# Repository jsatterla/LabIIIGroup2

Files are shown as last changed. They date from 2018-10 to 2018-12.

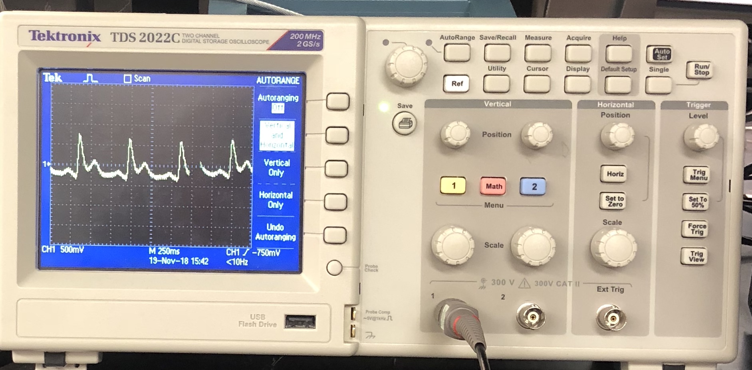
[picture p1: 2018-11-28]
Biomedical/EKG/Best Oscilloscope Reading.JPG

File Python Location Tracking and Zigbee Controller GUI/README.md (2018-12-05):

Python 3.7 program communicating with TI CC2640R2F LaunchPad for location tracking with Time of Flight. Sends network commands to XBee interfaced via RS232 breakout board. Uses pyserial for serial communication to XBee and CC2640R2F LaunchPad, and TkInter package for GUI.

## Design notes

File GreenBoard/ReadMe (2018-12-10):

## this file is of no importance. However, the green board files contained within this are slighly. lol

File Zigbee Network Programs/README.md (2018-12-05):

Folder for 2 MSP430 programs that control the model home's devices.

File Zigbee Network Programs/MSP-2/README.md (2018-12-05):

C program for MSP430 controlling 1 stepper motor and 1 BS170 n channel FET.

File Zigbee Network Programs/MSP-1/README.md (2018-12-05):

MSP #1 program to control 4 LED's and 1 computer fan

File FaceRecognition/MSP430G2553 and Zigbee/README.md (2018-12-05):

This folder contains the files to communicate MSP430 microcontroller with Zigbee module to open a door with stepper motor.

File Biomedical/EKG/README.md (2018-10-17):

Information and schematics related to the EKG portion of the project

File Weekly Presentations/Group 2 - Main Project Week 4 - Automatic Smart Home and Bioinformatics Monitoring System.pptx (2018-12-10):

## SMART Home

Group 2:
John Satterla [Team Lead] – Computer Engineer – Wireless Connectivity
Zachary Eakerns – Electrical Engineer – Biomedical Station
Zarka McClung – Computer Engineer – Facial Recognition
Christian Jensen – Electrical Engineer – Voice Recognition

## Last Week's Deliverables

John Satterla

- Test ToF Launchpads for accuracy depending on environment
- Develop Zigbee network protocol for sending and receiving meaningful data

Zachary Eakerns

- Built and begin testing filters
- Begin writing and testing software for peak detection

Zarka McClung

- Research Algorithm and try to implement it
- Completed webcam code to test Algorithm with face detection code

Christian Jensen

- Design and order parts for relay circuit
- Research Raspberry Pi Smart home front ends

## System Overview

LEDs to represent Lights

LCD screen represents TV

Door can be opened automatically via facial recognition or control from central processing station via Zigbee

Full size automatic door with facial recognition

Small Scale House Model

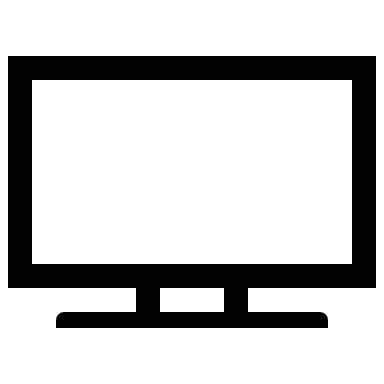
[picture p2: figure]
Television

Biomedical Station

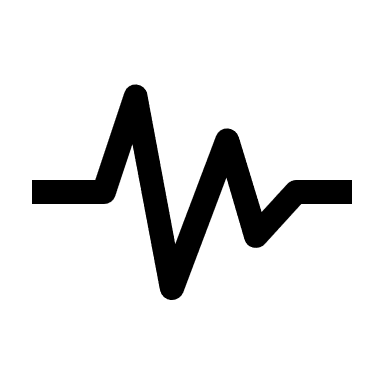
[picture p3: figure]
Heartbeat

Biomedical station gets EKG, heart rate, and blood oxygenation of the user, relays information to the Central processing station. Zigbee module takes commands from central processing station to control devices

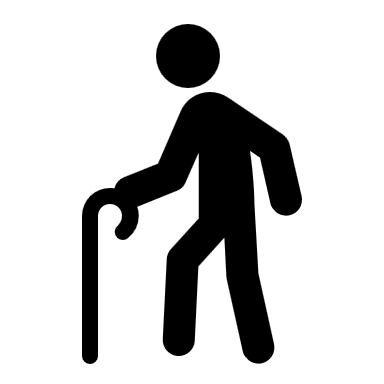
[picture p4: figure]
Person with Cane
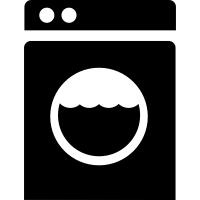
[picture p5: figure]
Image result for washer icon

Computer fan to represent ceiling fan

Servo based washer representation

Portable Location Detection Device

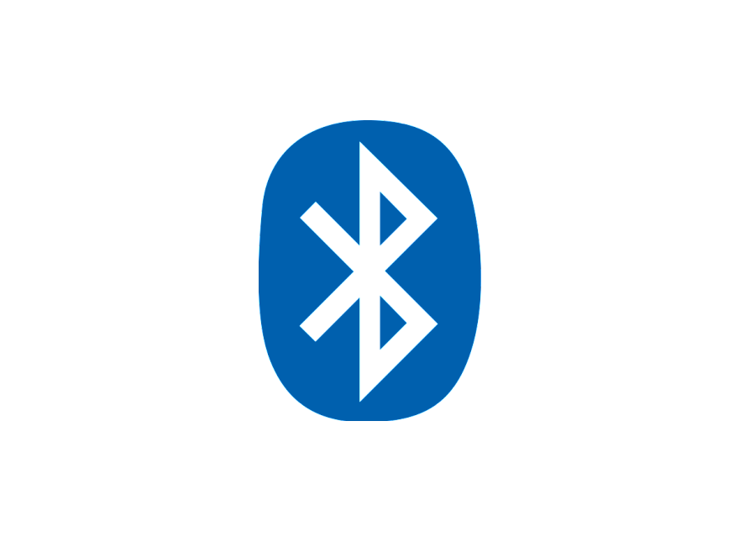
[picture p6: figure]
Image result for bluetooth logo

Portable BLE Time of Flight device reacts to movements of user throughout the room and devices turn on inside the small scale model

Central processing Station, with Voice Recognition

Central processing station (computer) displays system information and can control devices via voice commands. Communicates with rest of devices via Zigbee

Bluetooth ToF Beacon

Zigbee Module

Microcontroller

John Satterla

## Tracking Location of the Patient Monitor

- Ideally work indoors, so using GPS not preferred because of accuracy and not able to get fix inside of buildings
- BLE ToF – Bluetooth Time of Flight
  - Time of Flight is used to estimate range by measuring the round trip delay of an RF packet exchange
  - At least two devices needed, and operate generally as a master and a slave, where the master calculates average round trip delay for hundreds of packets to be as accurate as possible (try to reduce error from interference, other RF related differences) [ref]

John Satterla

## Bluetooth Time of Flight

- Experimental Bluetooth Time of Flight stack from Texas Instruments allows patients location to be tracked by calculating the round-trip time and RSSI of packets from the ToF initiator and responder

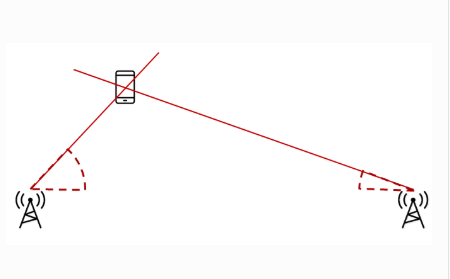
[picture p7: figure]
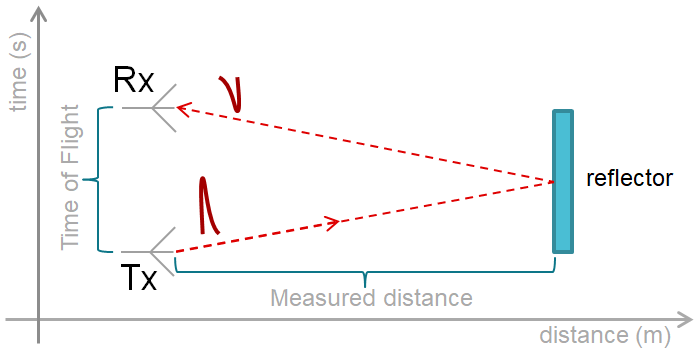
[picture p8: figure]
A screenshot of a cell phone Description generated with very high confidence

ToF Responder

ToF Initiator

[1]

John Satterla

## BLE ToF – Further Testing

- Testing was done to see if interference was cause of problem with location returning negative values
- Testing was to no success after testing in environment with limited 2.4GHz interference, although it did seem better than basement lab
- In contact with TI on how to improve performance, was directed to some optimization tools in the software that will be tested this week

John Satterla

## BLE ToF – Further Testing

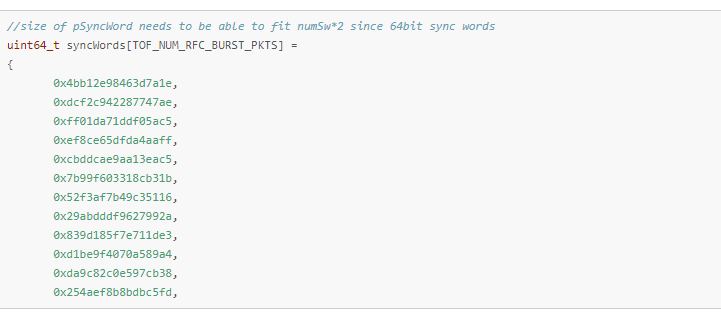
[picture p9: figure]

Going to try and increase the number of syncwords, which serve as almost ‘ACKs’ that sync each ToF flight packet with each other

[2]

John Satterla

## Changing Software

- Using Code Composer Studio in conjunction with launchpad is far too slow to accurately graph data every 2 ms for EKG readings
- To fix this, research into using Python along with UART communication via BlueSMiRF is underway
- Microcontroller will still be coded in Code Composer Studio, however receiving data and graphing it will be done through Python

## Python

- Data can be graphed quickly in Python by using the matplotlib library
- Python will store the data received by the BlueSMiRF [1] into a vector and then graph the value
- Things to be mindful of include making sure baud rate of both the communication method and the microcontroller are sufficient, and that vector can delete past values incase the machine is left on for a long amount of time

## Matplotlib

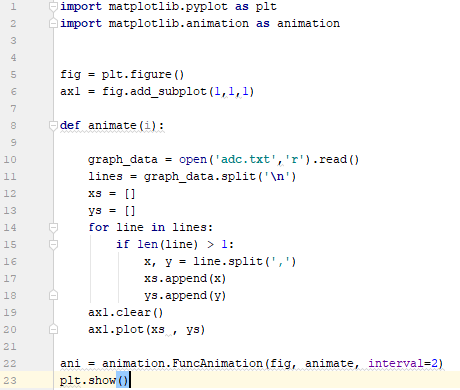
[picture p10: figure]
A screenshot of a social media post Description generated with very high confidence
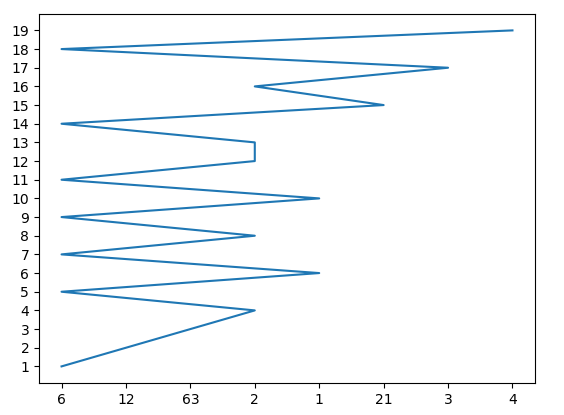
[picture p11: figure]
A close up of a logo Description generated with very high confidence

## Instability In Circuitry

- While amplification circuit seems to work, as well as the filters removing transmission line noise, the output is unstable at lower frequencies, varying by as much as 20%
- Could be due to breadboard, faulty parts, or faulty measuring equipment
- Further work will go into identifying issue once code catches up since switching to Python created a setback

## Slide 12

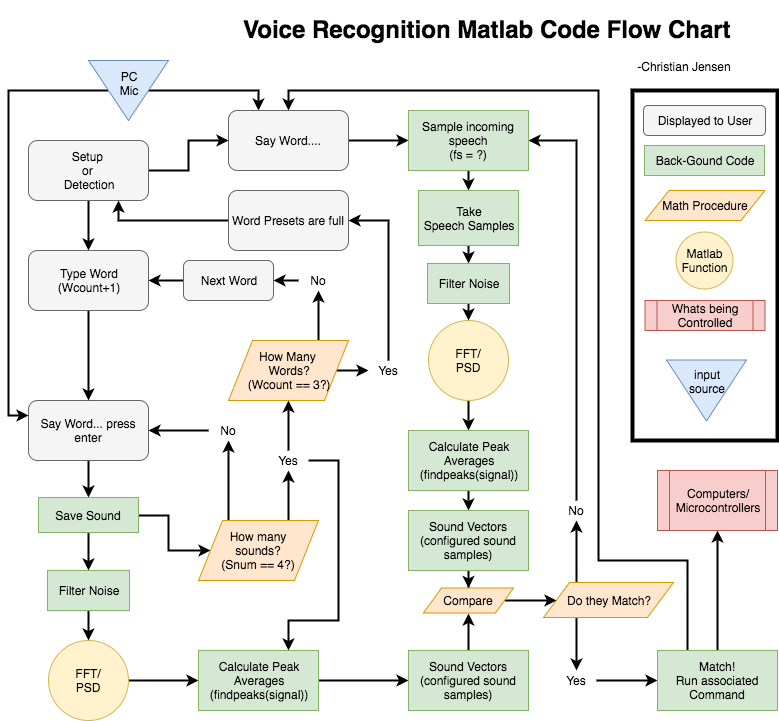
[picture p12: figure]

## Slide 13

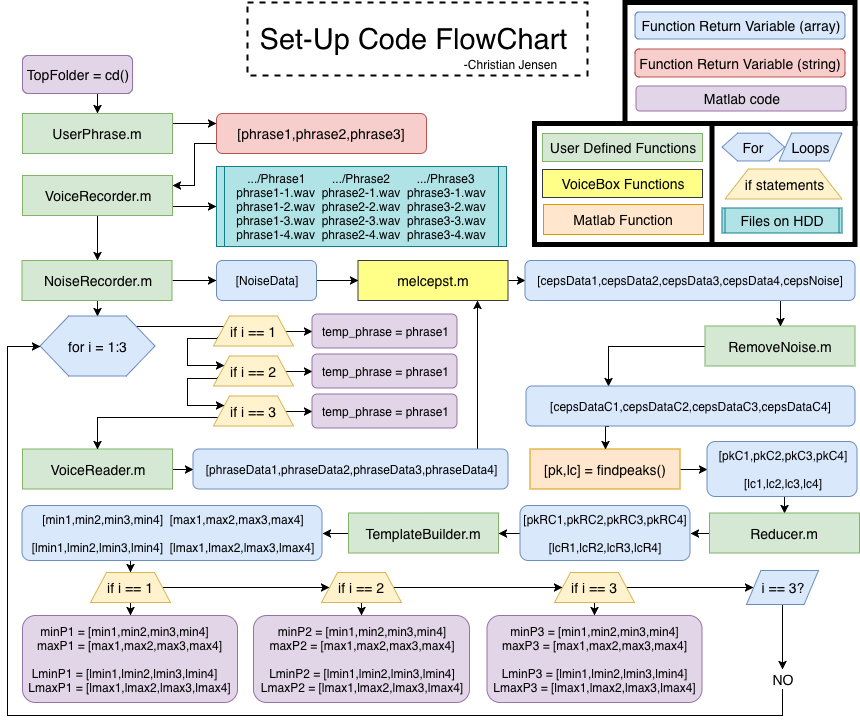
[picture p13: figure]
A screenshot of a parking meter Description generated with high confidence

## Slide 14

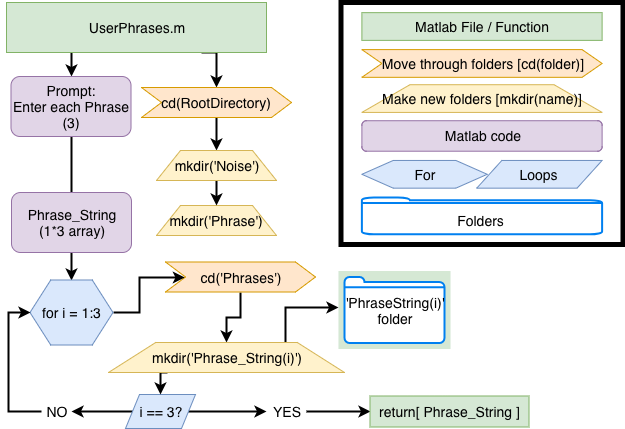
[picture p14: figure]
A screenshot of a cell phone Description generated with very high confidence

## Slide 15

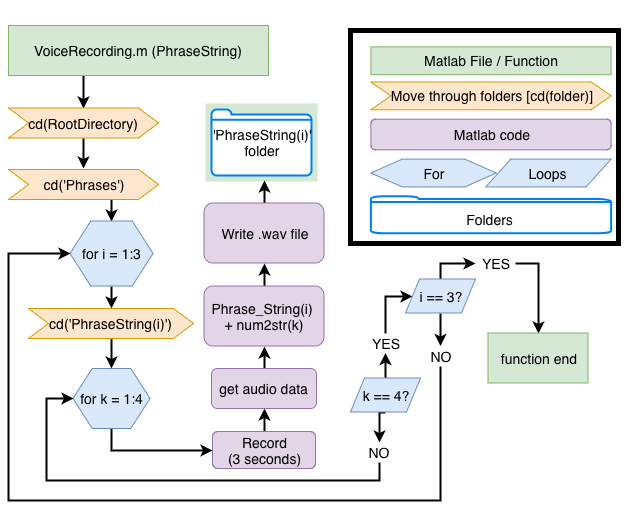
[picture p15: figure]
A screenshot of a cell phone Description generated with very high confidence

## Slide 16

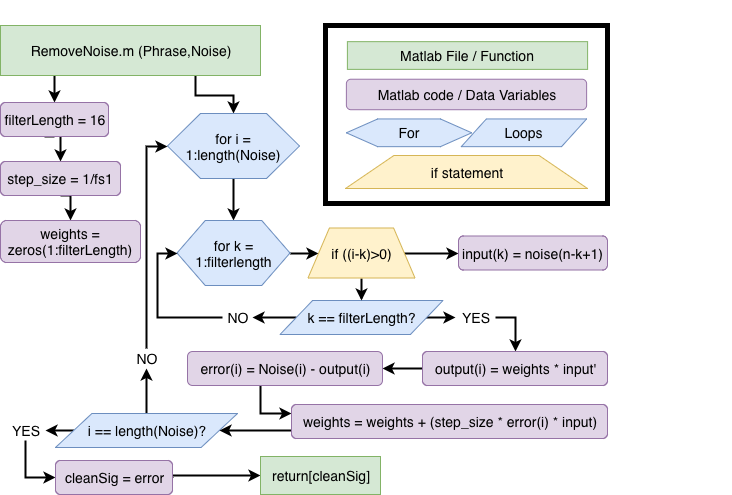
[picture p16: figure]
A screenshot of a cell phone Description generated with very high confidence

Least Mean Squared adaptive filter

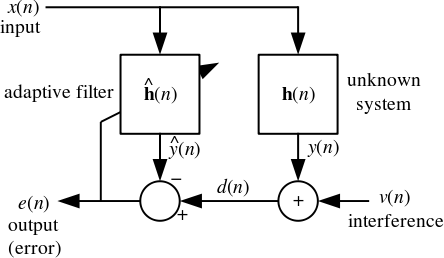
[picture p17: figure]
A close up of a logo Description generated with very high confidence

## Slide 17

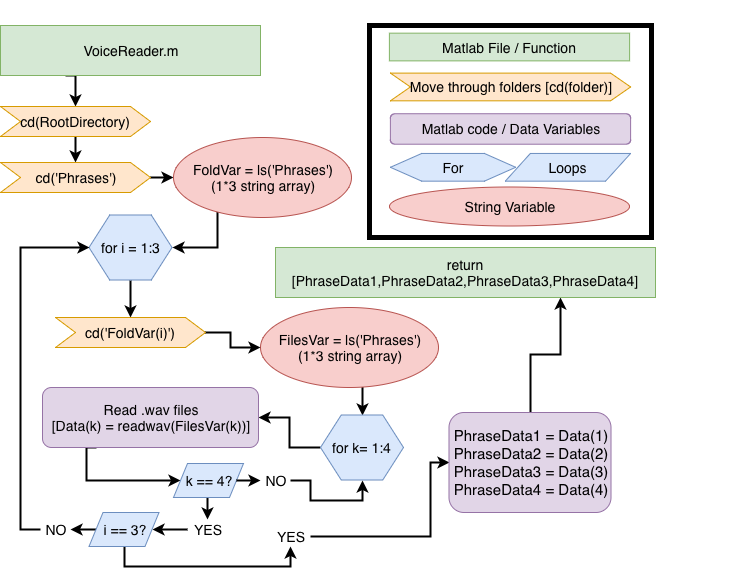
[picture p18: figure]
A screenshot of a cell phone Description generated with very high confidence

## Cepstrum

- C[n] = Cepstrum
  - IDFT of Log-spectrum over time
  - Inverse of frequency called Quefrecy

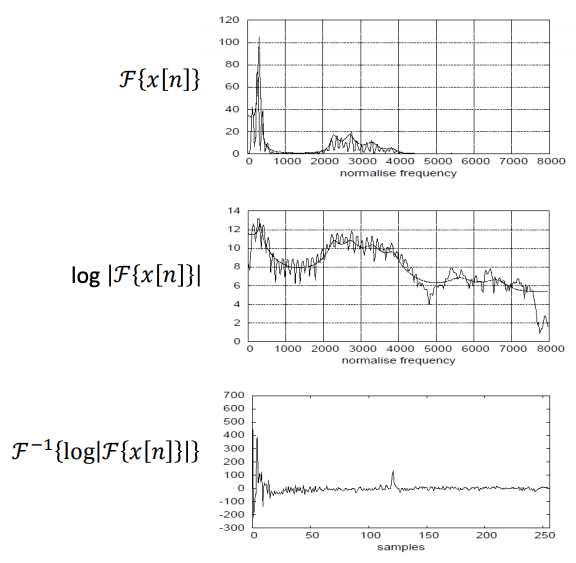
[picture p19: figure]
A close up of a map Description generated with high confidence

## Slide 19

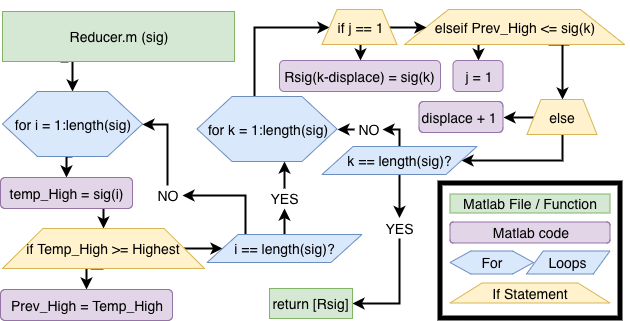
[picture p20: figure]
A screenshot of a cell phone Description generated with very high confidence
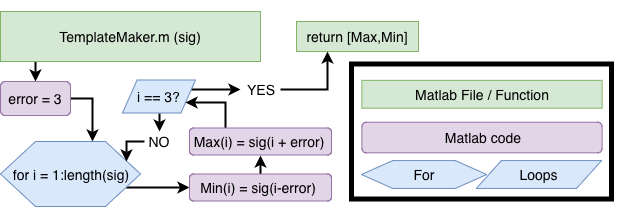
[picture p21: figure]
A screenshot of a cell phone Description generated with very high confidence

## Voice Recognition Methods

Process:
1. Ask user to set up phrases before
  1. Type name of phrase
  2. Speak the phrase (3x times)
  3. Find the PSD of the signal
  4. Set peaks as template
2. Speech recognition
  1. Poll for incoming phrases
  2. Sample input
  3. Find the PSD of the signal
  4. Compare peaks with Template

- Matlab [7]
  - Using the computer and its microphone to detect voice
    - Allows for easier integration with the entire project
    - Using the Voicebox Toolbox [9]
    - Contains many voice and audio related functions

*The system will be speaker dependent
(Only recognizing one specific person's commands)

## Update on Face Recognition and Hardware

- Completed Face Recognition software to detect user successfully. Will be tweaking it more down the road after main goal to open the door is completed.
- Currently working on best route to send wireless signal to open the door for the user.
- Will be using Zigbee module (ordered through stockroom) to send command to Master Zigbee Module (John's Zigbee), then Master module will send command to MCU to open the door
- Researching on methods, which motor to use to open the door.
- Will be working on code for Computer to Zigbee communication
- Once goal is accomplished, will be working on facial gesture detection to make recognition more secure

## Gantt Chart

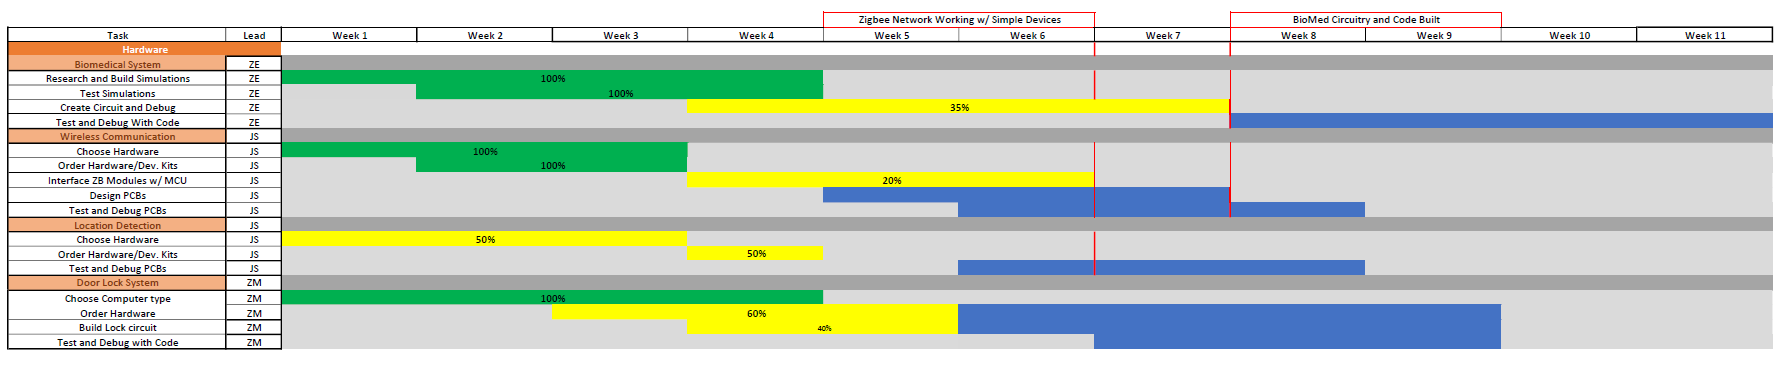
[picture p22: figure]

## Gantt Chart

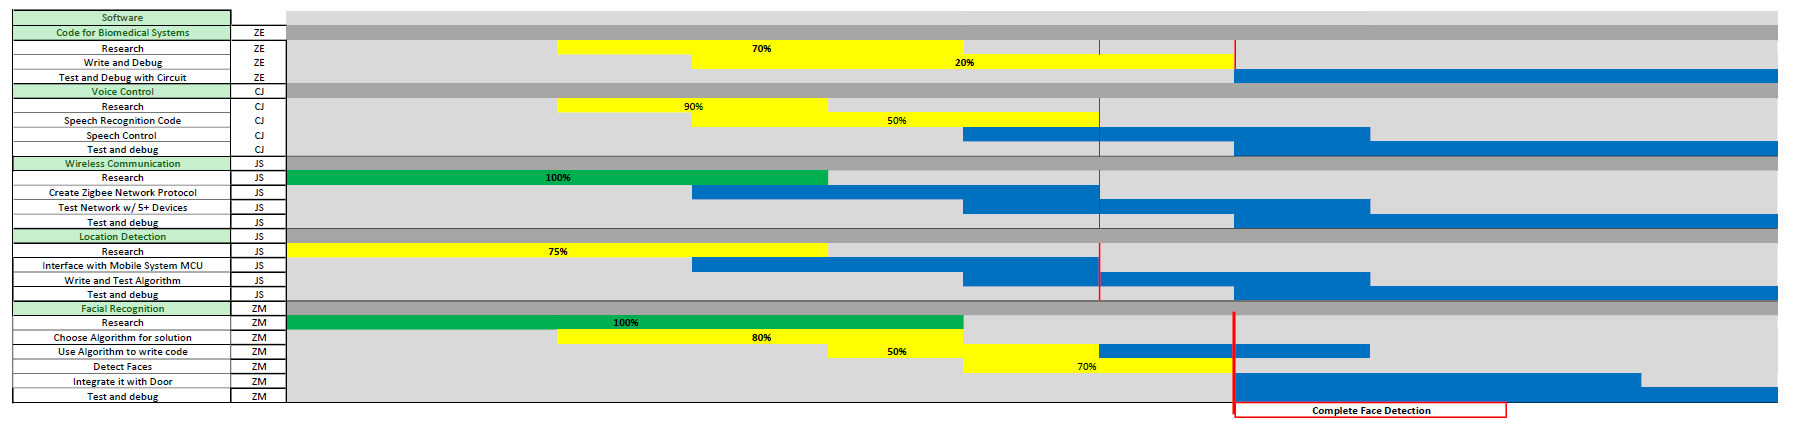
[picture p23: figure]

## Budget

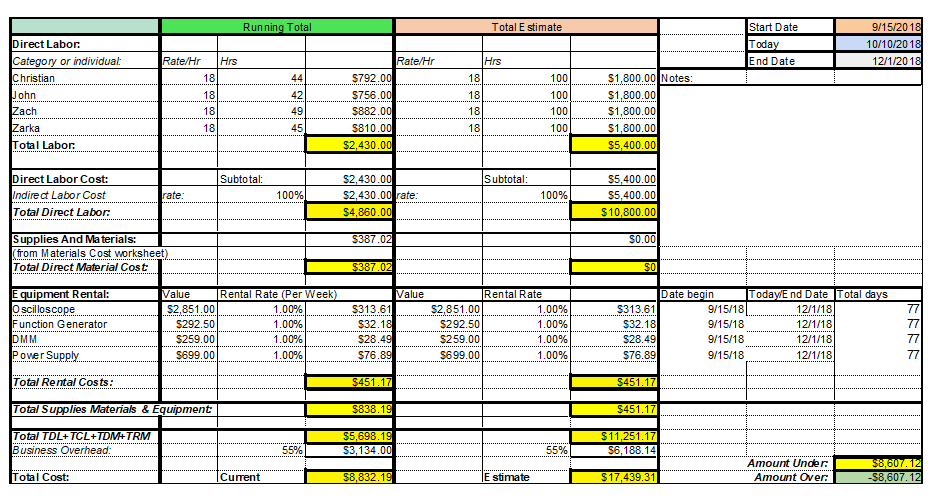
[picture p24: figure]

## Material Cost

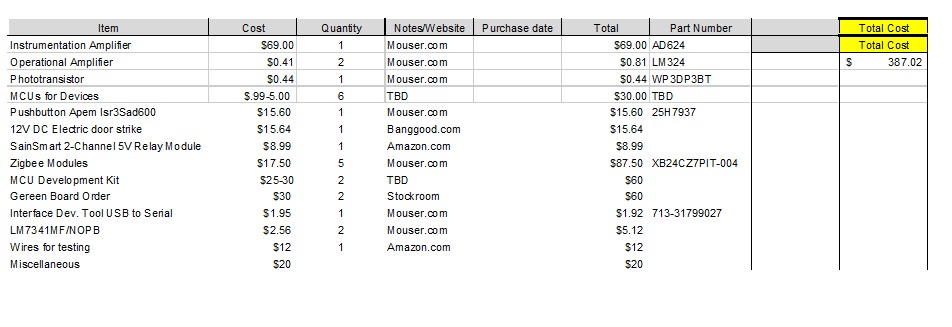
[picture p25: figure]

## Next Week's Deliverables

John Satterla

- Test ToF further with optimizations
- Send meaningful data over Zigbee network for logging of health data
- Start developing GUI for system monitoring and control

Zachary Eakerns

- Have Python communication with MCU ready for testing

Zarka McClung

- Hardware research
- Select method to open door
- Order some parts to begin testing

Christian Jensen

- Start sampling input words to find what fs to use
- Continue writing Matlab code
- Research Matlab controlling MCUs through computer

## References

1. “RN-42 Data Sheet.” [Online]. Available: https://cdn.sparkfun.com/datasheets/Wireless/Bluetooth/Bluetooth-RN-42-DS.pdf. [Accessed: 23-Oct-2018].
2. “Time Of Flight (TOF) Initiator,” TI Cloud Tools, 2018. [Online]. Available: http://dev.ti.com/tirex/#/?link=Software/SimpleLink CC2640R2 SDK/Examples/Development Tools/CC2640R2 LaunchPad/blestack/tof_initiator. [Accessed: 24-Oct-2018].

## Questions?

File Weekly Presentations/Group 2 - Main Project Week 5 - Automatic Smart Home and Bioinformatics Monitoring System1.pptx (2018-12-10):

## SMART Home

Group 2:
John Satterla – Computer Engineer – Wireless Connectivity
Zachary Eakerns – Electrical Engineer – Biomedical Station
Zarka McClung [Team Lead] – Computer Engineer – Facial Recognition
Christian Jensen – Electrical Engineer – Voice Recognition

## Last Week's Deliverables

John Satterla

- Test ToF further with optimizations
- Send meaningful data over Zigbee network for logging of health data
- Start developing GUI for system monitoring and control

Zachary Eakerns

- Have Python
communication with MCU ready for testing

Zarka McClung

- Hardware research
- Select method to open door
- Order some parts to begin testing

Christian Jensen

- Continue work on Recognition software
- Start green board design

## System Overview

LEDs to represent Lights

LCD screen represents TV

Door can be opened automatically via facial recognition or control from central processing station via Zigbee

Full size automatic door with facial recognition

Small Scale House Model

Biomedical Station

Biomedical station gets EKG, heart rate, and blood oxygenation of the user, relays information to the Central processing station. Zigbee module takes commands from central processing station to control devices

Computer fan to represent ceiling fan

Servo based washer representation

Portable Location Detection Device

Portable BLE Time of Flight device reacts to movements of user throughout the room and devices turn on inside the small scale model

Central processing Station, with Voice Recognition

Central processing station (computer) displays system information and can control devices via voice commands. Communicates with rest of devices via Zigbee

Bluetooth ToF Beacon

Zigbee Module

Microcontroller

John Satterla

## Tracking Location of the Patient Monitor

- Ideally work indoors, so using GPS not preferred because of accuracy and not able to get fix inside of buildings
- BLE ToF – Bluetooth Time of Flight
  - Time of Flight is used to estimate range by measuring the round trip delay of an RF packet exchange
  - At least two devices needed, and operate generally as a master and a slave, where the master calculates average round trip delay for hundreds of packets to be as accurate as possible (try to reduce error from interference, other RF related differences) [4]

John Satterla

## Tracking Location of the Patient Monitor

- For this, Texas Instruments has a experiential stack that I am going to evaluate and see what kind of performance I can get
- The tricky part will be using two masters that are positioned at two known points, and then connecting to the single slave on the patient to triangulate it’s position


Patient monitor

Master 2

Master 1

[3]

John Satterla

## BLE ToF – Further Testing

- Testing was done to see if interference was cause of problem with location returning negative values
- Testing was to no success after testing in environment with limited 2.4GHz interference, although it did seem better than basement lab
- In contact with TI on how to improve performance, was directed to some optimization tools in the software that will be tested this week

John Satterla

## BLE ToF – Further Testing


Going to try and increase the number of syncwords, which serve as almost ‘ACKs’ that sync each ToF flight packet with each other

[2]

John Satterla

## Graphical User Interface - Vision

- Relatively simple design, ability to monitor and manually control the connected devices

BioMedical Data

LED 1

LED 2

Fan

Washer

LED 3

Door

LED 4

TV

## Graphical User Interface – Early Development

- Using Python 3, with tkinter as GUI, and pyserial for communication to USB dongle with Xbee module


## Graphical User Interface – Early Development

- Using python 3, with tkinter as GUI, and pyserial for communication to USB dongle with Xbee module


## Graphical User Interface – Early Development Results

- Using python 3, with tkinter as GUI, and pyserial for communication to USB dongle with XBee module
- Simple for now, takes sliders and can send commands across Zigbee network
- Can also update the button or device’s status with commands from network
- Lots of lines for 2 buttons (>100), but serial integration and ability to monitor network is much easier in python
- Python will be easier to deal with medical data

## Graphical User Interface – Video Demo

- Using python 3, with tkinter as GUI, and pyserial for communication to USB dongle with Xbee module
- Simple for now, takes sliders and can send commands across Zigbee network
- Can also update the button or device’s status with commands from network
- Video: GUI on laptop computer, MSP430 Launchpad receiving power from USB hub with XBee conncected to Zigbee network for communication

Sending information to GUI (https://youtu.be/7rAZSsCwbYM)
Sending commands from GUI (https://youtu.be/zFmdJBd-_7U)

## Changing Software

- Using Code Composer Studio in conjunction with launchpad is far too slow to accurately graph data every 2 ms for EKG readings
- To fix this, research into using Python along with UART communication via BlueSMiRF is underway
- Microcontroller will still be coded in Code Composer Studio, however receiving data and graphing it will be done through Python

## Python

- Data can be graphed quickly in Python by using the matplotlib library
- Python will store the data received by the BlueSMiRF [2] into a vector and then graph the value
- Things to be mindful of include making sure baud rate of both the communication method and the microcontroller are matching, and that vector can delete past values in case the machine is left on for a long amount of time

## Matplotlib

A close up of a logo Description generated with very high confidence

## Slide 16

A screenshot of a cell phone Description generated with high confidence

## Instability In Circuitry

- While amplification circuit seems to work, as well as the filters removing transmission line noise, the output is unstable at lower frequencies, varying by as much as 20%
- Could be due to breadboard, faulty parts, or faulty measuring equipment
- Further work will go into identifying issue once code catches up since switching to Python created a setback

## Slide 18


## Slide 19

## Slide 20

A screenshot of a cell phone Description generated with very high confidence

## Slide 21

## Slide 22

A screenshot of a cell phone Description generated with very high confidence

Least Mean Squared adaptive filter

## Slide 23

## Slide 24

A screenshot of a cell phone Description generated with very high confidence

## MSP off the LaunchPad

- Requires a couple of extra components to function
  - 47kohm FB resistor [3]
  - 10µF Caps off the regulator[3

A display in a room Description generated with high confidence
A close up of a map Description generated with high confidence

## Green Board Design

A close up of a map Description generated with very high confidence

- MSP paired with an XBee Module
  - MSP430G IC
  - XBee Module on header pins
  - Design done in Eagle Cad
  - 3.3V LM2937 regulator located on board
    - Not final choice for regulator, just a place holder*
  - GND plane still needs to be added

A close up of a map Description generated with high confidence

## Face Recognition

A screen shot of a person Description generated with very high confidence

- Completed Face Recognition software to detect user successfully. Will be tweaking it more down the road after main goal to open the door is completed.
- Using around 20 dataset sample: 58%
- Used around 200 dataset sample: 60-65%

## Face Recognition

Conf is how much difference it has to match collected dataset.

"0" is a perfect match

## Radio 1 (master) configurationCOM9

A screenshot of a cell phone Description generated with very high confidence

## Radio 2 (slave) configuration COM8

Everything will be same, except it will act like a router instead of main co-ordinator.

## Bi-directional Communication- Mesh Network

A screenshot of a cell phone Description generated with very high confidence

Transmitted message in Blue
Received message in Red

## Bi-directional Communication – Mesh Network

Transmitted message in Blue
Received message in Red

## Opening door concept

A bathroom with a white door Description generated with high confidence

- Motor on one side with a string attached to a nail

A picture containing indoor, wall, floor, window Description generated with very high confidence

Stepper Motor

## Gantt Chart


## Gantt Chart


## Budget

## Material Cost


## Next Week's Deliverables

John Satterla

- Have working location tracking
- Determine all Zigbee protocol commands
- Begin integrating and building out GUI

Zachary Eakerns

- Have python graphing the ADC in real time
- Make headway on circuit instability

Zarka McClung

- Write Python code to send serial communication to Zigbee
- Establish motor code upon signal from Zigbee co-ordinator

Christian Jensen

- Finish green board design
- Continue writing Matlab code for voice recognition

## References

1. “MSP-EXP430G2 LaunchPad™ Development Kit.” SLAU318G, Jul-2010.
2. “RN-42 Data Sheet.” [Online]. Available: https://cdn.sparkfun.com/datasheets/Wireless/Bluetooth/Bluetooth-RN-42-DS.pdf. [Accessed: 23-Oct-2018].
3. S. Wendler, “MSP430G2xxx Stand Alone,” kaltpostde RSS. [Online]. Available: http://www.kaltpost.de/?page_id=1079. [Accessed: 31-Oct-2018].
4. “Time Of Flight (TOF) Initiator,” TI Cloud Tools, 2018. [Online]. Available: http://dev.ti.com/tirex/#/?link=Software/SimpleLink CC2640R2 SDK/Examples/Development Tools/CC2640R2 LaunchPad/blestack/tof_initiator. [Accessed: 24-Oct-2018].

## Questions?

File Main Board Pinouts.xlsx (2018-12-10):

MSP #1 |  | MSP #2 |  | 12v | fan
MSP | External | MSP | External | 5V | stepper driver
1.1 (RX) | DIN (XBEE) | 1.1 (RX) | DIN (XBEE) | 3.3V | LCD
1.2 (TX) | DOUT (XBEE) | 1.2 (TX) | DOUT (XBEE)
1 | LED 1
2 | LED 2
2.2 | LED 3
2.3 | LED 4
2.1 | Fan PWM

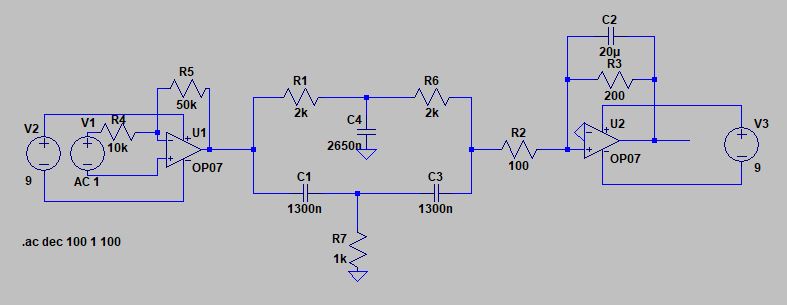
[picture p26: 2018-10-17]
Biomedical/EKG/ekgschem.JPG

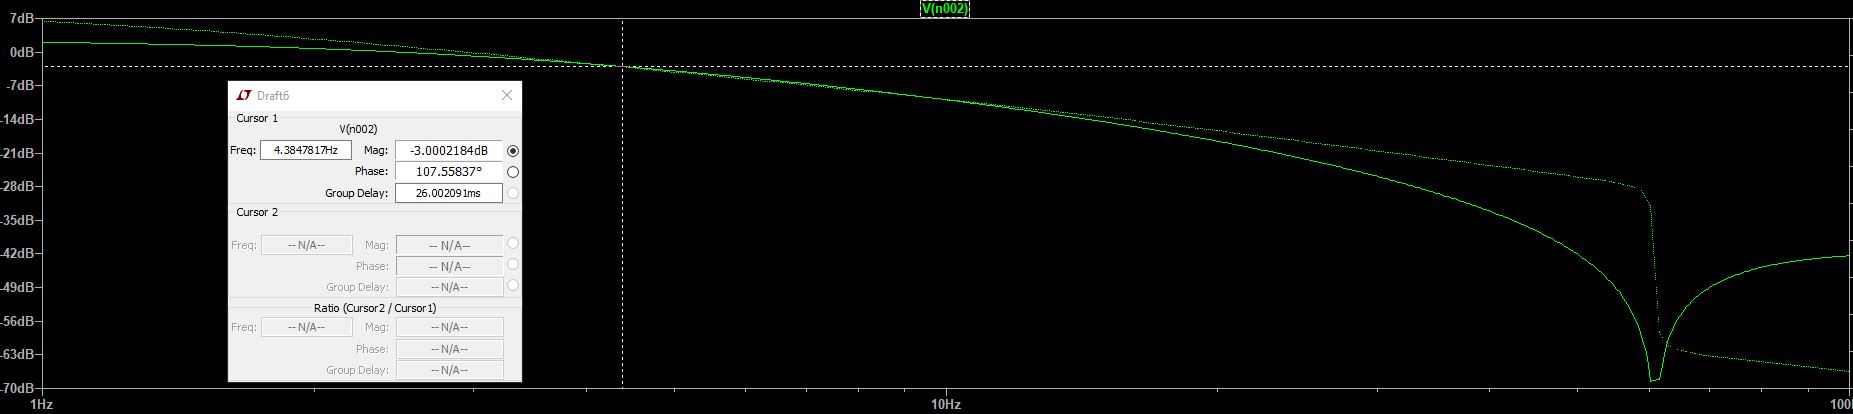
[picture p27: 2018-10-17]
Biomedical/EKG/ekggraph.JPG

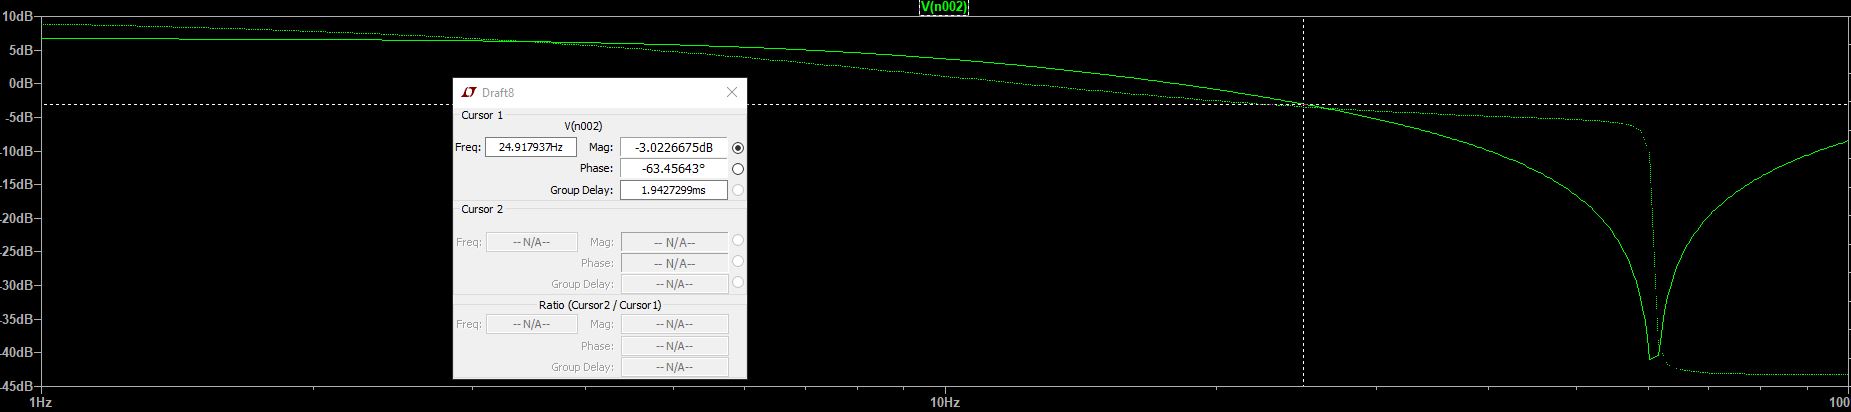
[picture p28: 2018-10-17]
Biomedical/Pulse Oximetry/oxygraph.JPG

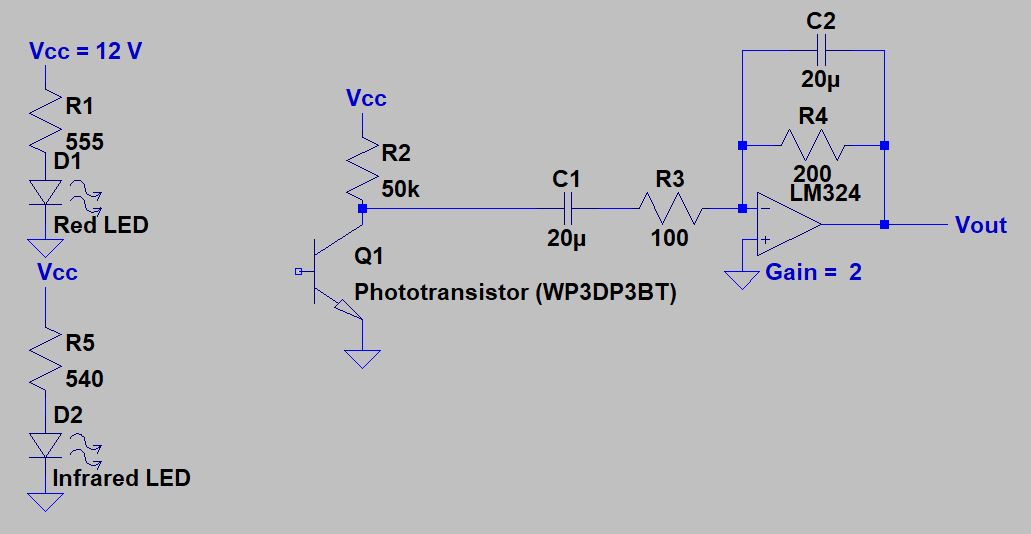
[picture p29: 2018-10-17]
Biomedical/Pulse Oximetry/oximetshcem.JPG

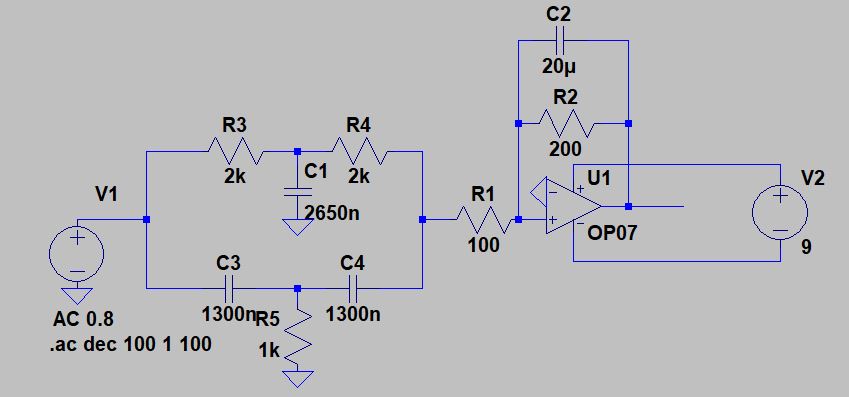
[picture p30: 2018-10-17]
Biomedical/Pulse Oximetry/oxyschem.JPG

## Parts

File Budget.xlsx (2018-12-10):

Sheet: Sheet1
 | Running Total |  |  | Total Estimate |  |  |  | Start Date | 2018-09-15
Direct Labor: |  |  |  |  |  |  |  | Today | 2018-12-01
Category or individual: | Rate/Hr | Hrs |  | Rate/Hr | Hrs |  |  | End Date | 2018-12-01
Christian | 18 | 75 | $1350.00 | 18 | 100 | $1800.00 | Notes:
John | 18 | 102 | $1836.00 | 18 | 100 | $1800.00
Zach | 18 | 94 | $1692.00 | 18 | 100 | $1800.00
Zarka | 18 | 95 | $1710.00 | 18 | 100 | $1800.00
Total Labor: |  |  | $4878.00 |  |  | $5400.00
Direct Labor Cost: |  | Subtotal: | $4878.00 |  | Subtotal: | $5400.00
Indirect Labor Cost | rate: | 100% | $4878.00 | rate: | 100% | $5400.00
Total Direct Labor: |  |  | $9756.00 |  |  | $10800.00
Supplies And Materials: |  |  | $361.86 |  |  | $0.00
(from Materials Cost worksheet)
Total Direct Material Cost: |  |  | $361.86 |  |  | $0
Equipment Rental: | Value | Rental Rate (Per Week) |  | Value | Rental Rate |  | Date begin | Today/End Date | Total days
Oscilloscope | $2851.00 | 1.00% | $313.61 | $2851.00 | 1.00% | $313.61 | 2018-09-15 | 2018-12-01 | 77
Function Generator | $292.50 | 1.00% | $32.18 | $292.50 | 1.00% | $32.18 | 2018-09-15 | 2018-12-01 | 77
DMM | $259.00 | 1.00% | $28.49 | $259.00 | 1.00% | $28.49 | 2018-09-15 | 2018-12-01 | 77
Power Supply | $699.00 | 1.00% | $76.89 | $699.00 | 1.00% | $76.89 | 2018-09-15 | 2018-12-01 | 77
Total Rental Costs: |  |  | $451.17 |  |  | $451.17
Total Supplies Materials & Equipment: |  |  | $813.03 |  |  | $451.17
Total TDL+TCL+TDM+TRM |  |  | $10569.02 |  |  | $11251.17
Business Overhead: |  | 55% | $5812.96 |  | 55% | $6188.14
 |  |  |  |  |  |  | Amount Under: |  | $1057.32
Total Cost: |  | Current | $16381.99 |  | Estimate | $17439.31 | Amount Over: |  | -$1057.32

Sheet: Materials Cost
Item | Cost | Quantity | Notes/Website | Purchase date | Total | Part Number | Total Cost
Instrumentation Amplifier | $69.00 | 1 | Mouser.com |  | $69.00 | AD624 | Total Cost
Operational Amplifier | $0.41 | 2 | Mouser.com |  | $0.81 | LM324 | $361.86
Phototransistor | $0.44 | 1 | Mouser.com |  | $0.44 | WP3DP3BT
MCUs for Devices | $2.10 | 10 | TBD |  | $21.00 | TBD
Stepper motor | $14.95 | 1 | sparkfun.com |  | $14.95 | ROB-09238
EasyDriver - Stepper Motor Driver | $14.95 | 1 | sparkfun.com |  | $14.95 | ROB-12779
SainSmart 2-Channel 5V Relay Module | $8.99 | 1 | Amazon.com |  | $8.99
Zigbee Modules | $17.50 | 5 | Mouser.com |  | $87.50 | XB24CZ7PIT-004
MCU Development Kit | $25-30 | 2 | TBD |  | $60
Gereen Board Order | $30 | 2 | Stockroom |  | $60
Interface Dev. Tool USB to Serial | $1.95 | 1 | Mouser.com |  | $1.92 | 713-31799027
LM7341MF/NOPB | $2.56 | 2 | Mouser.com |  | $5.12
Wires for testing | $12 | 1 | Amazon.com |  | $12
MSP430G2553 chip | $2.59 | 2 | mouser.com |  | $5.18

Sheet: Production Cost
Item | Cost | Quantity | Notes/Website | Total | Part Number | Total Cost
Instrumentation Amplifier | $69.00 | 1 | Mouser.com | $69.00 | AD624 | Total Cost
Operational Amplifier | $0.41 | 2 | Mouser.com | $0.81 | LM324 | $328.44
Phototransistor | $0.44 | 1 | Mouser.com | $0.44 | WP3DP3BT
MSP430G2533 | $1.14 | 3 | TBD | $3.42 | TBD
Pushbutton Apem Isr3Sad600 | $15.60 | 1 | Mouser.com | $15.60 | 25H7937
12V DC Electric door strike | $15.64 | 1 | Banggood.com | $15.64
SainSmart 2-Channel 5V Relay Module | $8.99 | 1 | Amazon.com | $8.99
Zigbee Modules | $17.50 | 5 | Mouser.com | $87.50 | XB24CZ7PIT-004
MCU Development Kit | $25-30 | 2 | TBD | $60
Gereen Board Order | $30 | 2 | Stockroom | $60
Interface Dev. Tool USB to Serial | $1.95 | 1 | Mouser.com | $1.92 | 713-31799027
LM7341MF/NOPB | $2.56 | 2 | Mouser.com | $5.12

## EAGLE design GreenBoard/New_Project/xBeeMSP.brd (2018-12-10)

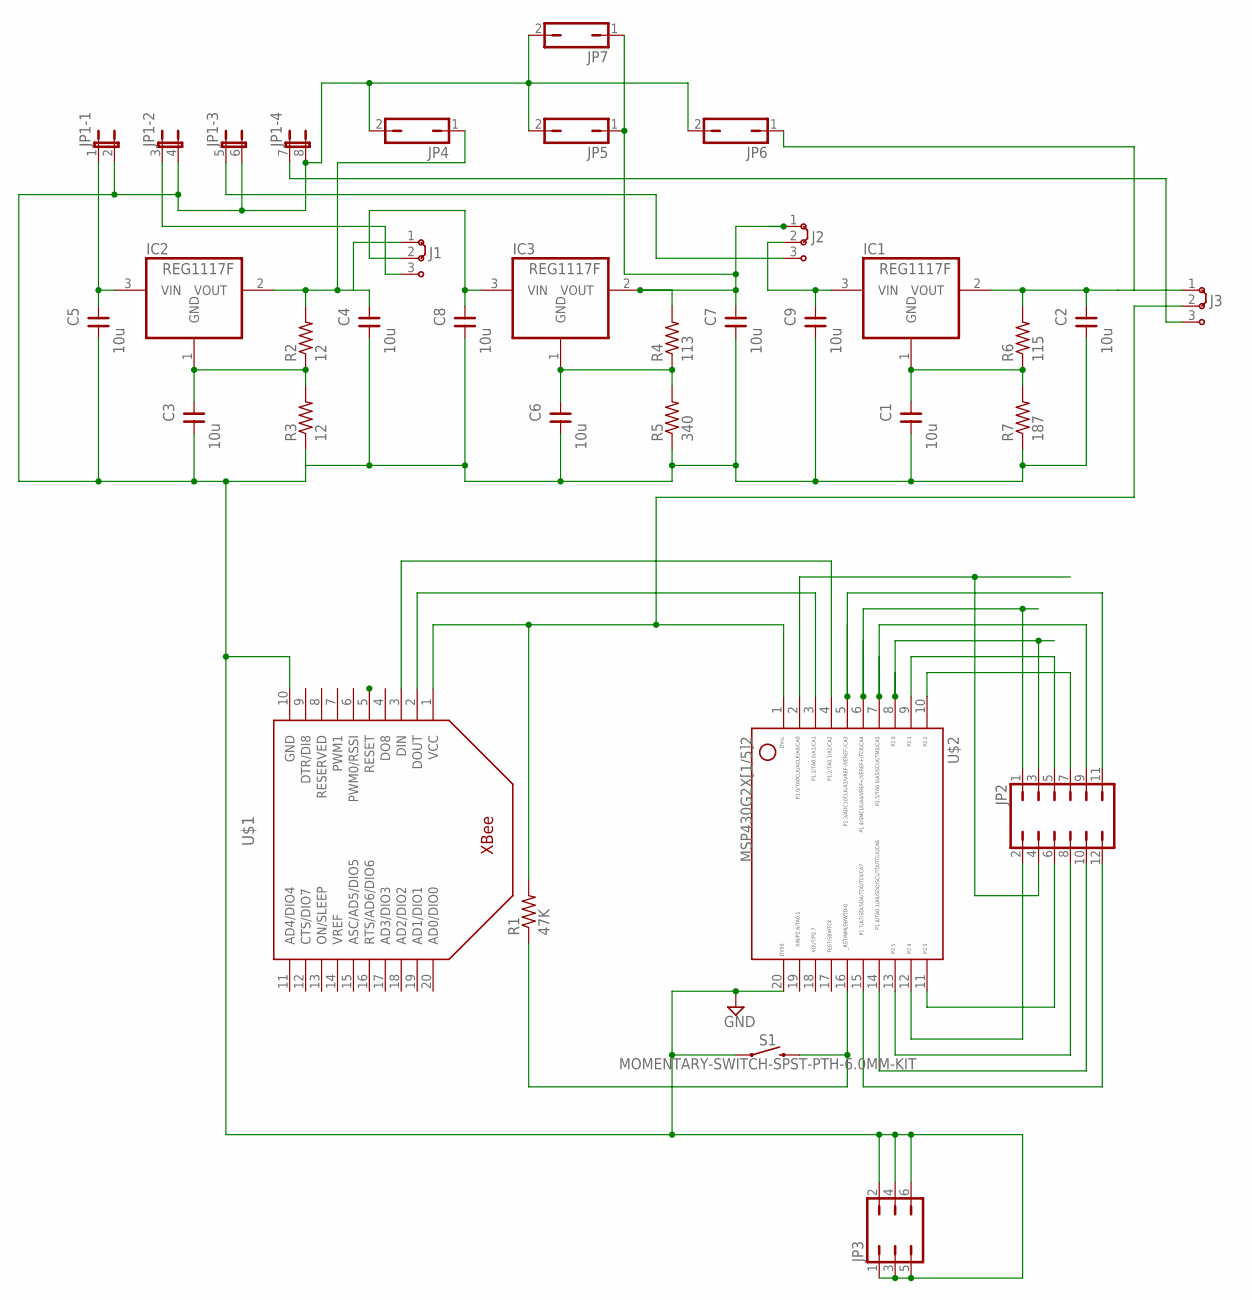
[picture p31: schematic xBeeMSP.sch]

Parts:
C1, C2, C3, C4, C5, C6, C7, C8, C9: 10u; C020-035X018
IC1, IC2, IC3: REG1117F; DD-3
J1, J2, J3: J2X2MM; 04C
JP1: JP4QE; JP4Q
JP2: JP6Q
JP3: JP3Q
JP4, JP5, JP6, JP7: JP1Q; JP1
R1: 47K; 0207/10
R2, R3: 12; 0207/10
R4: 113; 0207/10
R5: 340; 0207/10
R6: 115; 0207/10
R7: 187; 0207/10
S1: MOMENTARY-SWITCH-SPST-PTH-6.0MM-KIT; TACTILE_SWITCH_PTH_6.0MM_KIT
U$1: XBEE
U$2: G2X[1/5]2---N20; N20

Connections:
3.3VOUT: C2.2, IC1.2 (VOUT), J3.1, JP6.1, R6.2
5VIN: C9.2, IC1.3 (VIN), J2.2
5VOUT: C7.2, IC3.2 (VOUT), J2.1, JP5.1, JP7.1, R4.2
12VIN: C8.2, IC3.3 (VIN), J1.2
12VOUT: C4.2, IC2.2 (VOUT), J1.1, JP4.1, R2.2
BACKUP-5VIN: J2.3, JP1.5 (1)
BACKUP-12VIN: J1.3, JP1.3 (1)
BACKUP-VCC: J3.3, JP1.7 (1)
GND: C1.1, C2.1, C3.1, C4.1, C5.1, C6.1, C7.1, C8.1, C9.1, JP1.2, JP1.4 (2), JP1.6 (2), JP1.8 (2), JP3.1, JP3.2, JP3.3, JP3.4, JP3.5, JP3.6, JP4.2, JP5.2, JP6.2, JP7.2, R3.1, R5.1, R7.1, S1.1, U$1.5 (RESET), U$1.10 (GND), U$2.20
unnamed: U$1.2 (DOUT), U$2.3
unnamed: U$1.3 (DIN), U$2.4
unnamed: JP2.4, U$2.2
unnamed: R1.1, S1.3 (2), U$2.16
unnamed: JP2.9, U$2.7
unnamed: JP2.3, U$2.8
unnamed: JP2.12, U$2.15
unnamed: JP2.11, U$2.5
unnamed: JP2.5, U$2.9
unnamed: JP2.1, U$2.6
unnamed: JP2.10, U$2.14
unnamed: JP2.7, U$2.10
unnamed: JP2.8, U$2.13
unnamed: JP2.2, U$2.12
unnamed: JP2.6, U$2.11
unnamed: C3.2, IC2.1 (GND), R2.1, R3.2
unnamed: C1.2, IC1.1 (GND), R6.1, R7.2
unnamed: C6.2, IC3.1 (GND), R4.1, R5.2
unnamed: C5.2, IC2.3 (VIN), JP1.1
VCC: J3.2, R1.2, U$1.1 (VCC), U$2.1

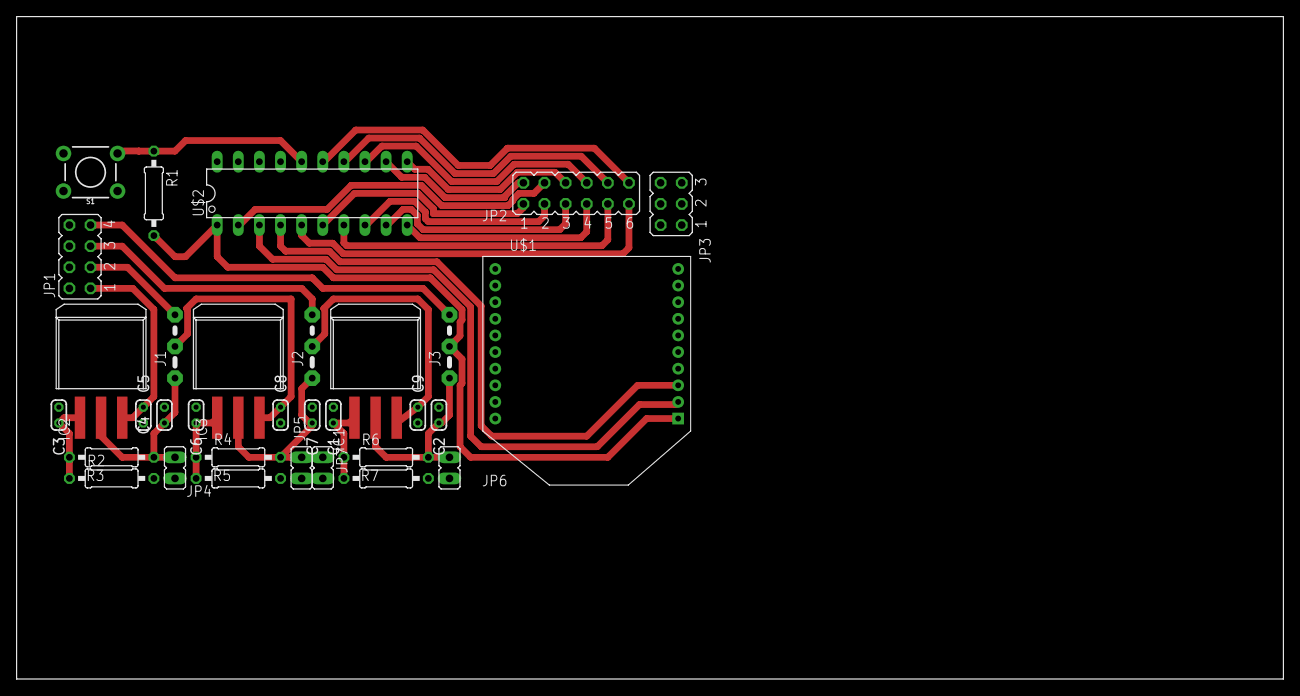
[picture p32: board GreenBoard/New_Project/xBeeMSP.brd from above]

Board: 2 copper layers, 152.4 x 79.7 mm, 32 parts (0 on the bottom side), 29 nets.

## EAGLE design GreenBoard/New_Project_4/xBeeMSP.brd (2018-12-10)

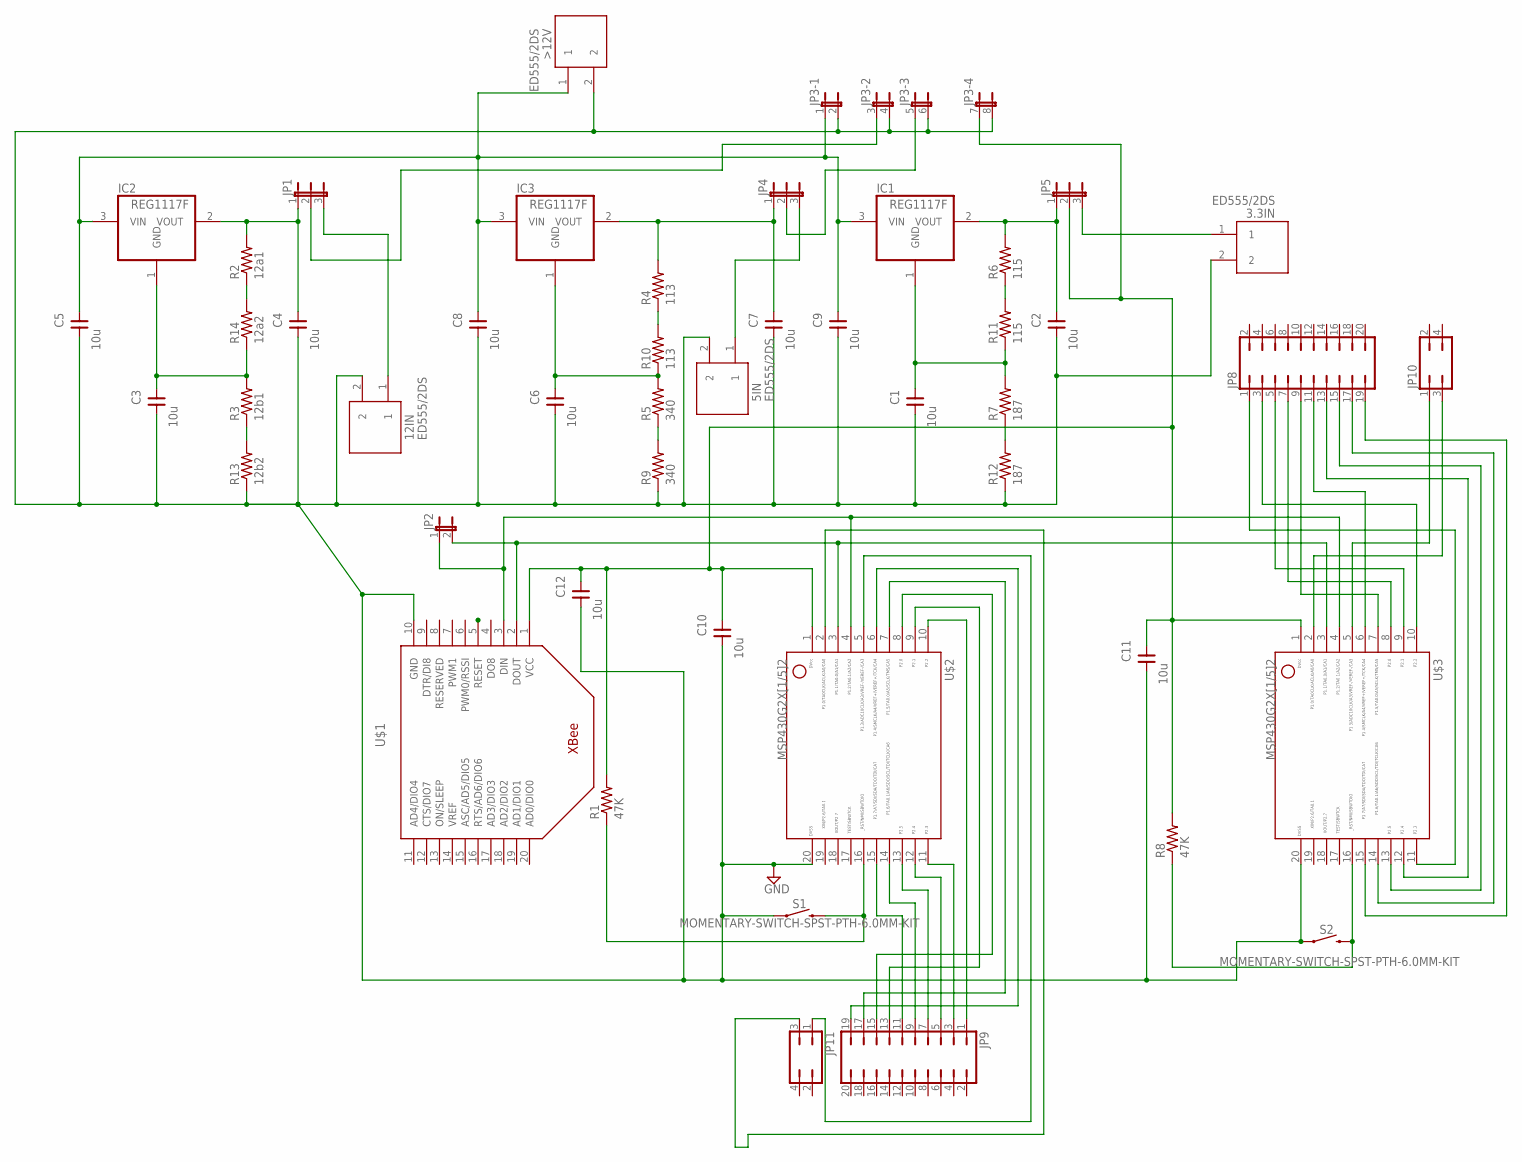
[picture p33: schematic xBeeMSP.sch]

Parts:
3.3IN, 5IN, 12IN: ED555/2DS
>12V: ED555/2DS
C1, C2, C3, C4, C5, C6, C7, C8, C9, C10, C11, C12: 10u; C020-035X018
IC1, IC2, IC3: REG1117F; DD-3
JP1, JP4, JP5: JP2E; JP2
JP2: JP1E; JP1
JP3: JP4QE; JP4Q
JP8, JP9: JP10Q
JP10, JP11: JP2Q
R1, R8: 47K; 0207/10
R2: 12a1; 0207/10
R3: 12b1; 0207/10
R4, R10: 113; 0207/10
R5, R9: 340; 0207/10
R6, R11: 115; 0207/10
R7, R12: 187; 0207/10
R13: 12b2; 0207/10
R14: 12a2; 0207/10
S1, S2: MOMENTARY-SWITCH-SPST-PTH-6.0MM-KIT; TACTILE_SWITCH_PTH_6.0MM_KIT
U$1: XBEE
U$2, U$3: G2X[1/5]2---N20; N20

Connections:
3.3VOUT: C2.2, IC1.2 (VOUT), JP5.1, R6.2
5VOUT: C7.2, IC3.2 (VOUT), JP4.1, R4.2
12VOUT: C4.2, IC2.2 (VOUT), JP1.1, R2.2
GND: 3.3IN.2, 5IN.2, 12IN.2, >12V.2, C1.1, C2.1, C3.1, C4.1, C5.1, C6.1, C7.1, C8.1, C9.1, C10.1, C11.1, C12.1, JP3.2, JP3.4 (2), JP3.6 (2), JP3.8 (2), R9.1, R12.1, R13.1, S1.1, S2.1, U$1.5 (RESET), U$1.10 (GND), U$2.20, U$3.20
unnamed: JP2.2, U$1.2 (DOUT), U$2.3, U$3.3
unnamed: JP9.3, U$2.11
unnamed: JP2.1, U$1.3 (DIN), U$2.4, U$3.4
unnamed: R1.1, S1.3 (2), U$2.16
unnamed: JP9.1, U$2.10
unnamed: JP9.13, U$2.9
unnamed: JP9.15, U$2.8
unnamed: JP9.17, U$2.7
unnamed: JP9.5, U$2.12
unnamed: JP9.19, U$2.6
unnamed: JP11.1, U$2.5
unnamed: JP11.3, U$2.2
unnamed: JP9.7, U$2.13
unnamed: JP9.9, U$2.14
unnamed: R8.1, S2.3 (2), U$3.16
unnamed: JP9.11, U$2.15
unnamed: JP10.3, U$3.2
unnamed: JP10.1, U$3.5
unnamed: JP3.5 (1), JP4.2
unnamed: JP8.3, U$3.10
unnamed: R2.1, R14.2
unnamed: JP8.1, U$3.11
unnamed: R4.1, R10.2
unnamed: JP8.5, U$3.9
unnamed: JP8.7, U$3.8
unnamed: JP8.9, U$3.7
unnamed: JP8.11, U$3.6
unnamed: JP8.13, U$3.12
unnamed: C6.2, IC3.1 (GND), R5.2, R10.1
unnamed: JP8.15, U$3.13
unnamed: JP8.17, U$3.14
unnamed: JP8.19, U$3.15
unnamed: R6.1, R11.2
unnamed: R5.1, R9.2
unnamed: C1.2, IC1.1 (GND), R7.2, R11.1
unnamed: R7.1, R12.2
unnamed: C3.2, IC2.1 (GND), R3.2, R14.1
unnamed: 12IN.1, JP1.3
unnamed: R3.1, R13.2
unnamed: 5IN.1, JP4.3
unnamed: >12V.1, C5.2, C8.2, C9.2, IC1.3 (VIN), IC2.3 (VIN), IC3.3 (VIN), JP3.1
unnamed: 3.3IN.1, JP5.3
unnamed: JP1.2, JP3.3 (1)
VCC: C10.2, C11.2, C12.2, JP3.7 (1), JP5.2, R1.2, R8.2, U$1.1 (VCC), U$2.1, U$3.1

Board: 2 copper layers, 47 parts (3 on the bottom side), 48 nets, no tracks yet.

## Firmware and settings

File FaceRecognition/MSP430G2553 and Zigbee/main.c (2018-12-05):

#include <msp430.h>
#include <stdint.h>
#include "math.h"

/*Program for Controller of Zigbee Test Network,
 * adapted from msp430g2xx3_usci_uart_standard_transceiver.c example
 * by Nima Eskandari at Texas Instruments
 */
/******************************************************************************
**************************UART Initialization *********************************
******************************************************************************/


//------------------------------------------------------------------------------
// Definition of Constants
//------------------------------------------------------------------------------
//#define LED       0x01       //  %00000001    ; Port pin position P1.0
//#define RX       0x02       //  %00000010    ; Port pin position P1.1
//#define TX     0x04       //  %00000100    ; Port pin position P1.2

#define STEP     0x08       //    %00001000    ; Port pin position P1.3
#define DIR      0x10       //    %00010000    ; Port pin position P1.4

//#define MS1      0x20       //    %00100000    ; Port pin position P1.5
//#define MS2      0x40       //    %01000000    ; Port pin position P1.6
//#define ENABLE   0x80       //    %10000000    ; Port pin position P1.7

//#define PB_CW   0x01         // %00000001    ; Port pin position P2.0
//#define PB_ACW  0x02         // %00000010    ; Port pin position P2.1

//#define PB_CW_N   0x10       // %00010000    ; Port pin position P2.4
//#define PB_ACW_N 0x20        // %00100000    ; Port pin position P2.5

#define SMCLK_11500     0
#define SMCLK_9600      1
#define ACLK_9600       2

#define UART_MODE       SMCLK_9600

//------------------------------------------------------------------------------
// Definition of Variables
//-----------------------------------------------------------------------------
// RAM variables go here (word = int/short, byte = char)
unsigned int j;
unsigned int z;
unsigned int y;
unsigned int counter;
unsigned int count;
unsigned int stepNumber;
unsigned int DELAY_COUNT=0;

char buffer[0];
char doorClosed='B';
int x = 0;

//------------------------------------------------------------------------------
// Function prototypes
void setup()
{
    // Set up Port 1
    P1DIR |= STEP+DIR; // set P1.3, P1.4 as output

    // Set up Port 2 (all pin input)
    //P2REN |= PB_ACW+PB_CW; // enable internal resistance
    //P2OUT |= PB_ACW+PB_CW; // set internal resistance as pull-down

    P1SEL = BIT1 + BIT2;       // P1.1 = RXD, P1.2=TXD
    P1SEL2 = BIT1 + BIT2;

    // Set up calibrated DCO clock
    DCOCTL = 0;             // Select lowest DCOx and MODx settings
    BCSCTL1 = CALBC1_16MHZ;  // Set range
    DCOCTL = CALDCO_16MHZ;   // Set DCO step + modulation
}
void delay()
{
    // Load count constant and decrement until 0
    count = DELAY_COUNT;
    for(j=100;j>0;j--)
    {
        for(counter=DELAY_COUNT;counter>0;counter--)
        {
            do
            {
                count--;
            } while(count != 0);
            count=DELAY_COUNT;
        }
    }

}


void SendUCA0Data(uint8_t data)
{
    while (!(IFG2&UCA0TXIFG));                // USCI_A0 TX buffer ready?
    UCA0TXBUF = data;
}
void initUART()
{
    UCA0CTL1 |= UCSSEL_2;                     // SMCLK
    UCA0BR0 = 104;                            // 16MHz 9600
    UCA0BR1 = 0;                              // 16MHz 9600
    UCA0MCTL = UCBRS_0 + UCOS16 + UCBRF_3;    // Modulation UCBRSx = 0
    UCA0CTL1 &= ~UCSWRST;                     // **Initialize USCI state machine**
    IFG2 &= ~(UCA0RXIFG);
    IE2 |= UCA0RXIE;                          // Enable USCI_A0 RX interrupt
}

//******************************************************************************
// Main ************************************************************************
// Enters LPM0 if SMCLK is used and waits for UART interrupts. If ACLK is used *
// then the device will enter LPM3 mode instead. The UART RX interrupt handles *
// the received character and echoes it.                                       *
//******************************************************************************

void main()
{
    WDTCTL = WDTPW + WDTHOLD;                 // Stop WDT
    setup();
    initUART();



#if UART_MODE == ACLK_9600
    __bis_SR_register(LPM3_bits + GIE);       // Since ACLK is source, enter LPM3, interrupts enabled
#else
    __bis_SR_register(LPM0_bits + GIE);       // Since SMCLK is source, enter LPM0, interrupts enabled
#endif
}

//******************************************************************************
// UART RX Interrupt ***********************************************************
//******************************************************************************

#if defined(__TI_COMPILER_VERSION__) || defined(__IAR_SYSTEMS_ICC__)
#pragma vector=USCIAB0RX_VECTOR
__interrupt void USCI0RX_ISR(void)
#elif defined(__GNUC__)
void __attribute__ ((interrupt(USCIAB0RX_VECTOR))) USCI0RX_ISR (void)
#else
#error Compiler not supported!
#endif
{
    if (IFG2 & UCA0RXIFG)
    {
        uint8_t rx_val = UCA0RXBUF; //Must read UCxxRXBUF to clear the flag
       // SendUCA0Data(rx_val);
        buffer[x] = rx_val;
        if (buffer[x] == 'A'){
            P1OUT &= 0x00; //Pull direction pin low to move "FORWARD"
            DELAY_COUNT=10;
            for(z=13600;z>0;z--) //Loop the stepping enough times for motion to be visible
            {
                P1OUT|=STEP; //Trigger one step forward
                delay();
                P1OUT = ~STEP; //Pull step pin low so it can be triggered again
                delay();
            }
           delay();
            P1OUT |= DIR; //Pull direction pin high to move "REVERSE"
            DELAY_COUNT=10;
            for(y=13600;y>0;y--) //Loop the stepping enough times for motion to be visible
            {
                P1OUT |= STEP+DIR; //Trigger one step forward
                delay();
                P1OUT = ~STEP+DIR; //Pull step pin low so it can be triggered again
                delay();
            }

            SendUCA0Data(doorClosed);
        }
        x++;
    }
}

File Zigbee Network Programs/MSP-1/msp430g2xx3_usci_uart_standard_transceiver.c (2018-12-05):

#include <msp430.h>
#include <stdint.h>

/*Program for Controller of Zigbee Test Network,
 * adapted from msp430g2xx3_usci_uart_standard_transceiver.c example
 * by Nima Eskandari at Texas Instruments
 */
/******************************************************************************
**************************UART Initialization *********************************
******************************************************************************/

#define SMCLK_11500     0
#define SMCLK_9600      1
#define ACLK_9600       2

#define UART_MODE       SMCLK_9600

char buffer[400];
int x = 0;

void SendUCA0Data(uint8_t data)
{
    while (!(IFG2&UCA0TXIFG));                // USCI_A0 TX buffer ready?
    UCA0TXBUF = data;
}
void initUART()
{
    UCA0CTL1 |= UCSSEL_2;                     // SMCLK
    UCA0BR0 = 104;                            // 16MHz 9600
    UCA0BR1 = 0;                              // 16MHz 9600
    UCA0MCTL = UCBRS_0 + UCOS16 + UCBRF_3;    // Modulation UCBRSx = 0
    UCA0CTL1 &= ~UCSWRST;                     // **Initialize USCI state machine**
    IFG2 &= ~(UCA0RXIFG);
    IE2 |= UCA0RXIE;                          // Enable USCI_A0 RX interrupt
}

/*******************************************************************************
***************************Device Initialization *******************************
********************************************************************************/

void initClockTo16MHz()
{
    if (CALBC1_16MHZ==0xFF)                  // If calibration constant erased
    {
        while(1);                            // do not load, trap CPU!!
    }
    DCOCTL = 0;                              // Select lowest DCOx and MODx settings
    BCSCTL1 = CALBC1_16MHZ;                  // Set DCO
    DCOCTL = CALDCO_16MHZ;
}

void initGPIO()
{
    P1SEL = BIT1 + BIT2;                      // P1.1 = RX, P1.2=TX
    P1SEL2 = BIT1 + BIT2;
    P1DIR |= 0x01;                            // Set P1.0 to output direction
    P2DIR |= BIT0 + BIT1 + BIT2 +BIT3;                     // port 2 all outputs
    P2SEL |= BIT1;

}

/******************************************************************************
***********************************Main ***************************************
****Enters LPM0 if SMCLK is used and waits for UART interrupts. The UART RX****
**********interrupt handles the received character and echoes it.**************
******************************************************************************/

void main()
{
    WDTCTL = WDTPW + WDTHOLD;                 // Stop WDT
    initClockTo16MHz();
    initGPIO();
    initUART();

    TA1CCR0 |= 640 - 1;
    TA1CCTL1 |= OUTMOD_7;
    TA1CCR1 |= 10;
    TA1CTL |= TASSEL_2 + MC_1;

    __bis_SR_register(GIE);       // Since ACLK is source, enter LPM3, interrupts enabled

}

/******************************************************************************
***************************UART RX Interrupt **********************************
******************************************************************************/

void __attribute__ ((interrupt(USCIAB0RX_VECTOR))) USCI0RX_ISR (void)
{
    if (IFG2 & UCA0RXIFG)
        {
            char rx_val = UCA0RXBUF; //Must read UCxxRXBUF to clear the flag
            buffer[x] = rx_val;         //place received value into buffer
            SendUCA0Data(buffer[x]);

            switch (buffer[x]){
                case '1':                   //turn off LED 1
                    P1OUT &= ~BIT0;
                    break;
                case '2':                   //turn on LED 1
                    P1OUT |= BIT0;
                    break;
                case '3':                   //turn off LED 2
                    P2OUT &= ~BIT0;
                    break;
                case '4':                   //turn on LED 2
                    P2OUT |= BIT0;
                    break;
                case '5':                   //turn off LED 3
                    P2OUT &= ~BIT2;
                    break;
                case '6':                   //turn on LED 3
                    P2OUT |= BIT2;
                    break;
                case '7':                   //turn off LED 4
                    P2OUT &= ~BIT3;
                    break;
                case '8':                   //turn on LED 4
                    P2OUT |= BIT3;
                    break;
                case 'G':                   //set fan to low
                    TA1CCR1 = 400;
                    break;
                case 'H':                   //set fan to high
                    TA1CCR1 = 600;
                    break;
                case 'I':                   //set fan to idle
                    TA1CCR1 = 0;
                    break;
            }
            x++;
        }

}

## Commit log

2018-11-22 Create Precision Amplifier Circuit Notes
2018-12-05 Stepper Motor and driver datasheet
    SM-42BYG011-25 Bipolar stepper motor is used with the easy driver to move motor upon receiving signal.

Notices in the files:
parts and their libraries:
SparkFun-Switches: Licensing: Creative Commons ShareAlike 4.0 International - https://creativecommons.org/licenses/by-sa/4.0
